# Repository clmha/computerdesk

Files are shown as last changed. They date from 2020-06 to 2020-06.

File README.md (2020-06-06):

# Bureau d'ordinateur
Un petit bureau d'ordinateur (code de projet CD1) avec un compartiment dissimulé dans le plan de travail inspiré du projet "Small Computer Desk" de [Build Something](https://www.buildsomething.com/plans/PB3DC397A2732E8EE/Small-Computer-Desk).

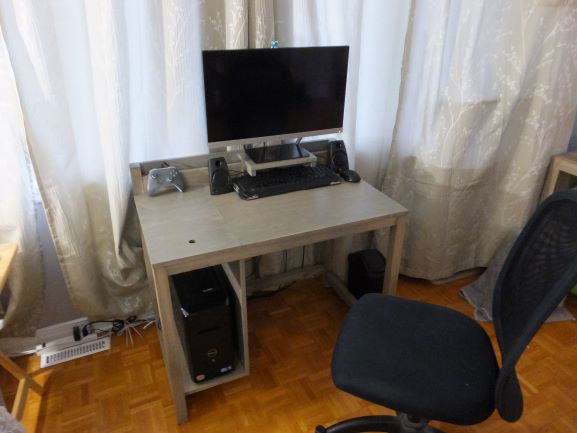
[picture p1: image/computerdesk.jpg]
Résultat final
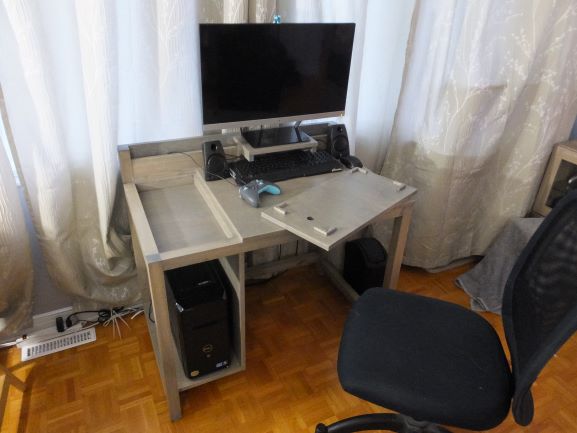
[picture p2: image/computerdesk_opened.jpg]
Résultat final, avec le compartiment ouvert
 

# Matériaux
Si vous ne faites aucune erreur de coupe, vous aurez besoin de :

* (1) goujon carré 3/8"x3/8"x4'
* (1) goujon carré 3/4"x3/4"x4'
* (4) latte 1 1/2"x1 1/2"x8'
* (1) planche 3/4"x3 1/2"x8'
* (1) feuille de contre-plaqué 3/4"x4'x8'
* (2) bande de chant 13/16"x25'

# Quincaillerie
* Colle à bois
* Vis pour trou en angle #8 2 1/2"
* Vis pour trou en angle #8 1"
* Vis à bois à tête plate #8 1 1/4"

# Outils nécessaires
Hormis les outils de base (p. ex. ruban à mesurer), vous aurez également besoin de :

* Gabarit pour faire des trous en angle;
* Perceuse/visseuse;
* Scie circulaire pour découper les panneaux;
* Scie à onglet pour découper précisement les lattes et les planches.

# Liste des documents
* CD1-ASY-001.pdf : dessin d'ensemble du projet avec la liste des pièces;
* CD1-ASY-002.pdf : dessin d'assemblage par étapes;
* CD1-MFG-001.pdf : le plan de coupe;
* CD1-MFG-001.pdf : le coût du projet;
* CD1-PRT-XYZ.pdf : le dessin de définition de la pièce numéro XYZ (notez que les pièces triviales n'ont pas de dessin de définition);
* CD1-REQ-001.pdf : le cahier des charges du bureau.

# Environnement de développement
* Windows 10 comme système d'exploitation;
* QCAD Professional pour les dessins techniques;
* LibreOffice 6.3.6 pour les documents;
* PDFtk pour manipuler les fichiers PDF;
* MinGW (mingw32-base-bin 2013072200) pour les outils de développement de base.

# Construire les artefacts
Avec l'environnement de développement correct, il vous suffit de lancer la commande "make" depuis une invite de commande cmd.exe à la racine du projet et les documents seront générés dans le répertoire "build".

En cas d'erreurs "'X' n'est pas reconnu en tant que commande interne ou externe [...]", vérifiez que les exécutables de LibreOffice, QCAD, PDFtk et MinGW sont dans votre PATH.

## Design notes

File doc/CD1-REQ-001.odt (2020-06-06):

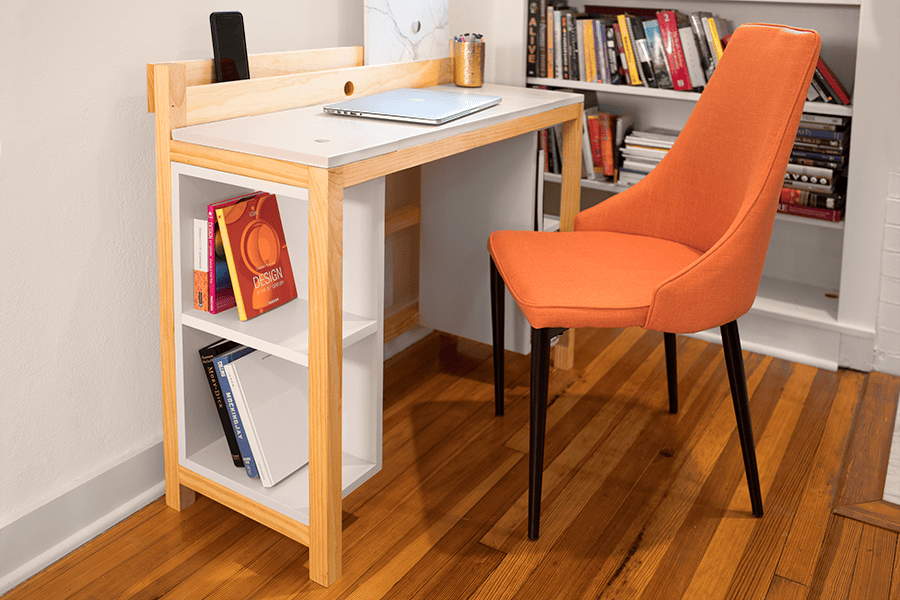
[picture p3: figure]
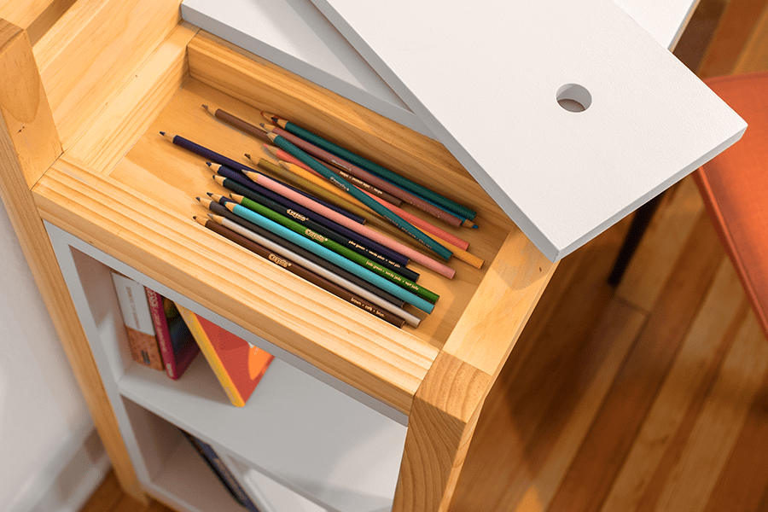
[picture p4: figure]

Figure 1 Exemple de bureau d’ordinateur [BS17]

CD1-REQ-001

Clément Hamel

2020-06-05

# Définitions

Lettre US 11×8 1/2 po

pi Pied (1 pi = 12 po)

po Pouce

# Références

BS17: Build Something, Small Computer Desk, 2017, https://www.buildsomething.com/plans/PB3DC397A2732E8EE/Small-Computer-Desk

# Vision

S’inspirer du bureau illustrée dans la Figure 1 pour remplacer le petit bureau que nous avons actuellement dans le salon.

L’étagère de gauche serait modifiée pour accueillir un ordinateur de bureau et étagère serait ajoutée au milieu du plan de travail pour surélever l’écran.

# Exigences

## Support d’écran

Le bureau doit avoir un support permettant de surélever un écran avec une base d’au moins 6 1/2×10 3/8 po afin d’être compatible avec notre écran.

## Emplacement pour le fauteuil

L’emplacement pour le fauteuil doit faire au moins 24 po de large afin de permettre à quelqu’un de se glisser avec notre fauteuil de bureau actuel sans être gêné.

La mesure de 24 po a été déterminée à partir de notre bureau actuel.

## Étagère pour l’ordinateur

Le bureau doit comporter une étagère pouvant contenir un ordinateur de bureau d’au moins 7×14 3/8×17 5/8 po (largeur×hauteur×profondeur) tout en gardant ses ports accessibles directement depuis l’avant et l’arrière du bureau.

Les dimensions minimales de l’ordinateur sont basées sur notre ordinateur actuel.

## Profondeur

Le bureau doit être suffisamment profond pour que :

1. l’écran soit à peu prêt à la distance d’un bras d’un utilisateur tapant au clavier (règle d’ergonomie);
2. que l’utilisateur puisse avoir un clavier et feuille au format Lettre US en avant de lui (cas d’utilisation de l’utilisateur recopiant un document).

## Largeur

Le bureau ne doit pas être plus large que 3 pi afin de rentrer dans l’espace disponible dans le salon.

## Finition

### Couleur

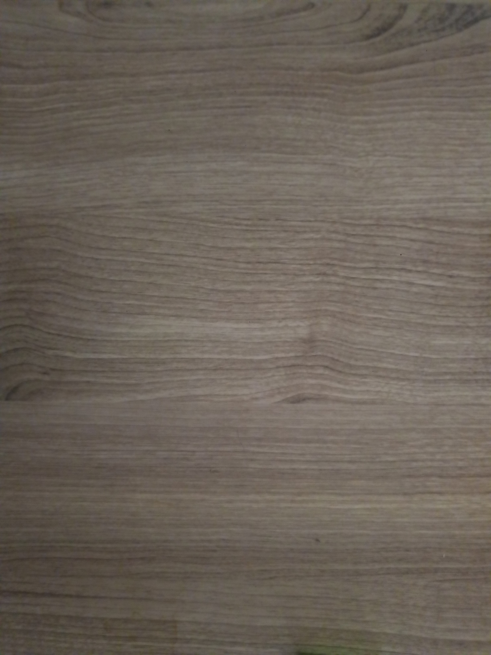
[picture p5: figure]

Figure 2 Échantillon de la couleur des meubles du salon.

Le bureau doit avoir une couleur similaire à celle de nos autres meubles du salon (cf. Figure 2).

### Protection

Le bureau doit être protégé contre l’exposition à l’eau et au soleil par un vernis transparent satiné pour des raisons esthétiques et un jour il devra être lavé et il est proche d’une fenêtre.

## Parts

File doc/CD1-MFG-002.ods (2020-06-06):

Item | Qté | Source | Prix unitaire HT | Rabais | Prix HT | Remarques
Bande de chant érable 13/16"x25' | 1 | RONA | 7,42 $ | 50,00% | 3,71 $
Bande de chant érable 13/16"x25' | 1 | BMR | 6,98 $ |  | 6,98 $
Latte 2x2x8' | 4 | BMR | 5,99 $ |  | 23,96 $
Latte 2x2x6' | 2 | BMR | 4,49 $ | 10,00% | 8,08 $ | Correction de mes erreurs de coupe.
Planche 1x4x8' | 1 | BMR | 6,99 $ | 10,00% | 6,29 $
Goujon 3/8"x4' | 1 | BMR | 0,98 $ | 10,00% | 0,88 $ | Pour dissimulation des têtes de vis.
Goujon carré 3/8"x3/8"x4' | 2 | BMR | 1,39 $ |  | 2,78 $
Goujon carré 3/4"x3/4"x4' | 1 | BMR | 3,59 $ |  | 3,59 $ | Car le banc de scie n'est pas disponible pour la refente.
Pré-teinture à l'huile 1 cup | 1 | BMR | 9,68 $ |  | 9,68 $
Teinture à l'huile couleur de base 1 qt | 1 | BMR | 17,28 $ |  | 17,28 $
Teinture à l'huile couleur naturel 1 qt | 1 | Canadian Tire | 16,99 $ |  | 16,99 $ | Pour pouvoir adapter la couleur de base aux différentes essences de bois.
Vernis transparent 1 qt | 1 | BMR | 25,99 $ |  | 25,99 $
Vis pour perçage à angle #8 1" BT100 | 1 | Canadian Tire | 6,99 $ |  | 6,99 $ | Pour remplacer les vis de 1 1/4" qui sont trop longues pour les panneaux de 11/16".
Vis pour perçage à angle #8 1 1/4" BT100 | 1 | Home Depot | 7,46 $ |  | 7,46 $
Vis pour perçage à angle #8 2 1/2" BT50 | 1 | Home Depot | 7,74 $ |  | 7,74 $
Vis à bois à tête plate #8 1 1/4" en acier électro-galvanisé BT100 | 0,06 | (stock) | 6,98 $ |  | 0,42 $
Panneau de particules plaqué érable 11/16"x4'x8' | 1 | BMR | 56,99 $ |  | 56,99 $
Coupe en quincaillerie | 2 | BMR | 2,00 $ |  | 4,00 $
Sous-total HT |  |  |  |  | 209,81 $
TPS |  |  |  |  | 10,49 $
TVQ |  |  |  |  | 20,93 $
Total TTC |  |  |  |  | 241,23 $

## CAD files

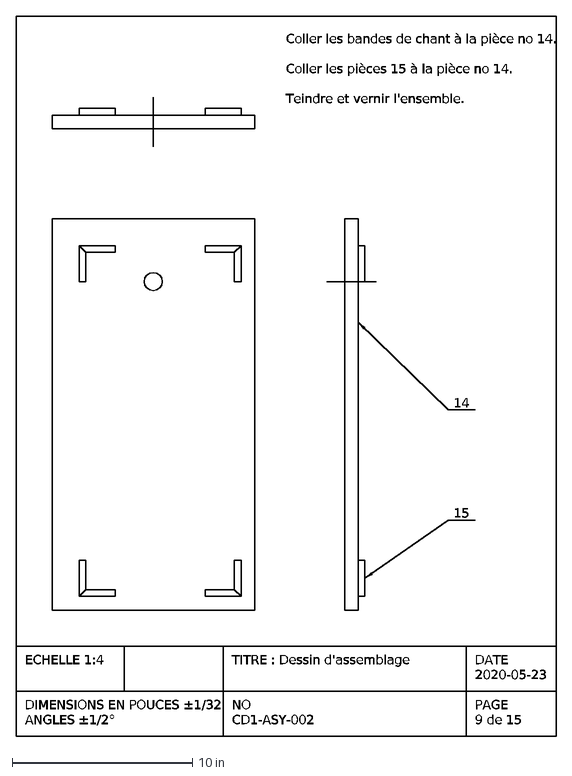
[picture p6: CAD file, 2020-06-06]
drawing/CD1-ASY-002_09.dxf
Coller les bandes de chant à la pièce no 14. Coller les pièces 15 à la pièce no 14. Teindre et vernir l'ensemble.
DIMENSIONS EN POUCES ±1/32 ANGLES ±1/2°
ECHELLE 1:4
NO CD1-ASY-002
TITRE : Dessin d'assemblage
PAGE 9 de 15
DATE 2020-05-23
15
14

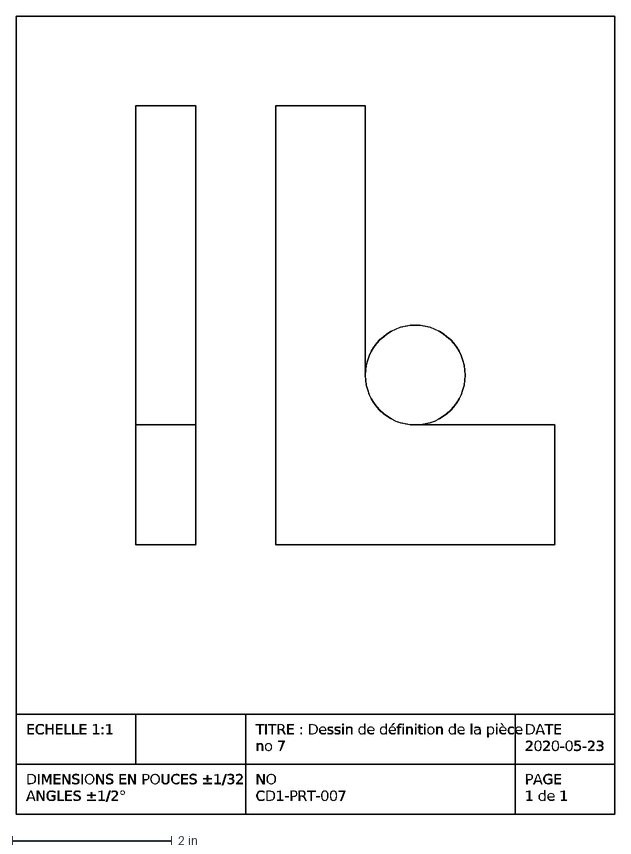
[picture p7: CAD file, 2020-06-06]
drawing/CD1-PRT-007.dxf
DIMENSIONS EN POUCES ±1/32 ANGLES ±1/2°
ECHELLE 1:1
NO CD1-PRT-007
TITRE : Dessin de définition de la pièce no 7
PAGE 1 de 1
DATE 2020-05-23

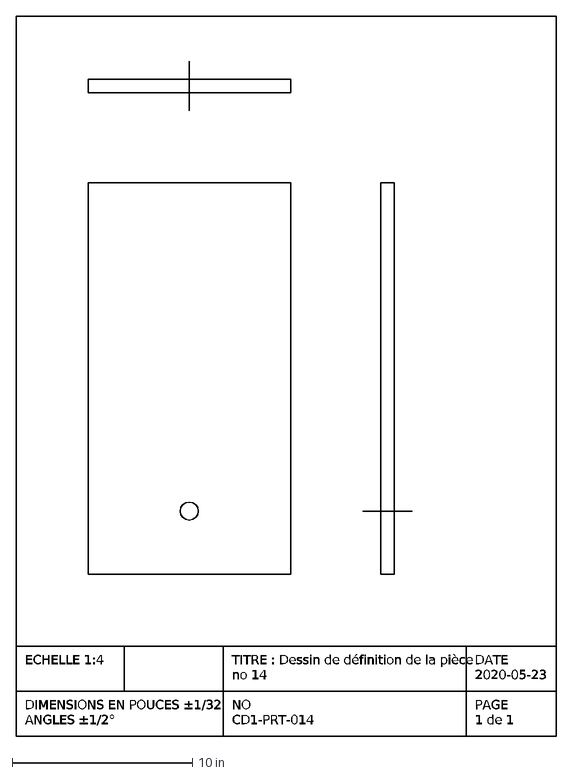
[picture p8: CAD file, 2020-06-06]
drawing/CD1-PRT-014.dxf
DIMENSIONS EN POUCES ±1/32 ANGLES ±1/2°
ECHELLE 1:4
NO CD1-PRT-014
TITRE : Dessin de définition de la pièce no 14
PAGE 1 de 1
DATE 2020-05-23

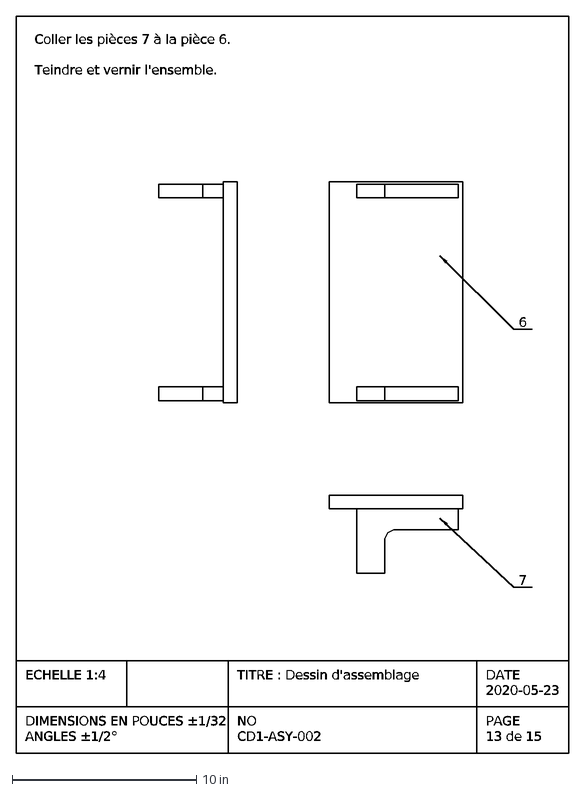
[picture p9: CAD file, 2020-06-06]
drawing/CD1-ASY-002_13.dxf
DIMENSIONS EN POUCES ±1/32 ANGLES ±1/2°
ECHELLE 1:4
NO CD1-ASY-002
TITRE : Dessin d'assemblage
PAGE 13 de 15
DATE 2020-05-23
Coller les pièces 7 à la pièce 6. Teindre et vernir l'ensemble.
6
7

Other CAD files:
drawing/CD1-ASY-002_15.dxf
drawing/CD1-ASY-002_08.dxf
drawing/CD1-ASY-002_10.dxf
drawing/CD1-ASY-002_01.dxf
drawing/CD1-ASY-002_11.dxf
drawing/CD1-ASY-001_3.dxf
drawing/CD1-ASY-001_1.dxf
drawing/CD1-ASY-001_2.dxf
drawing/CD1-ASY-002_07.dxf
drawing/CD1-ASY-002_02.dxf
drawing/CD1-ASY-002_12.dxf
drawing/CD1-PRT-003.dxf
drawing/CD1-ASY-002_05.dxf
drawing/CD1-ASY-002_06.dxf
drawing/CD1-ASY-002_03.dxf
drawing/CD1-ASY-002_04.dxf
drawing/CD1-ASY-002_14.dxf
drawing/CD1-MFG-001.dxf

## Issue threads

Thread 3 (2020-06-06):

CD1-ASY-002 - Emplacement des pré-perçages

clmha, 2020-06-06:
À la page 6, les pré-perçages sur la pièce no 3 devraient être décalés afin d’être centrés avec le centre des pièces no 7 pour l’assemblage à la page 15.

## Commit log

2020-06-06 Importation du projet
    Les documents, les dessins et les utilitaires existaient déjà mais n'étaient pas sous contrôle de version.
    [CD1-ASY-001_1.dxf, CD1-ASY-001_2.dxf, CD1-ASY-001_3.dxf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]
2020-06-06 MàJ du README
    Ajout des photos.
2020-06-06 Rédaction du README
    Donne la liste des matériaux, de la quincaillerie et des outils nécessaires pour construire le bureau plus la description des documents et comment les générer à nouveau.
    Profite également de cette opportunité pour enlever les manipulations du PATH qui étaient dans "make.bat". Cela dépend trop de comment est configuré l'ordinateur du développeur pour être partagé à tr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
2020-06-06 Typo
    Il manquait l'extension de certains fichiers.
